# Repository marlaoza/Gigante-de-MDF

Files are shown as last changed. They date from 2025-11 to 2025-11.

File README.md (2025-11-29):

```
      _,---.   .=-.-.    _,---.   ,---.      .-._        ,--.--------.    ,----.  
  _.='.'-,  \ /==/_ /_.='.'-,  \.--.'  \    /==/ \  .-._/==/,  -   , -\,-.--` , \ 
 /==.'-     /|==|, |/==.'-     /\==\-/\ \   |==|, \/ /, |==\.-.  - ,-./==|-  _.-` 
/==/ -   .-' |==|  /==/ -   .-' /==/-|_\ |  |==|-  \|  | `--`\==\- \  |==|   `.-. 
|==|_   /_,-.|==|- |==|_   /_,-.\==\,   - \ |==| ,  | -|      \==\_ \/==/_ ,    / 
|==|  , \_.' )==| ,|==|  , \_.' )==/ -   ,| |==| -   _ |      |==|- ||==|    .-'  
\==\-  ,    (|==|- \==\-  ,    (==/-  /\ - \|==|  /\ , |      |==|, ||==|_  ,`-._ 
 /==/ _  ,  //==/. //==/ _  ,  |==\ _.\=\.-'/==/, | |- |      /==/ -//==/ ,     / 
 `--`------' `--`-` `--`------' `--`        `--`./  `--`      `--`--``--`-----``

                     ,----.                ___                  _,---.  
      _,..---._   ,-.--` , \        .-._ .'=.'\  _,..---._   .-`.' ,  \ 
    /==/,   -  \ |==|-  _.-`       /==/ \|==|  /==/,   -  \ /==/_  _.-' 
    |==|   _   _\|==|   `.-.       |==|,|  / - |==|   _   _Y==/-  '..-. 
    |==|  .=.   /==/_ ,    /       |==|  \/  , |==|  .=.   |==|_ ,    / 
    |==|,|   | -|==|    .-'        |==|- ,   _ |==|,|   | -|==|   .--'  
    |==|  '='   /==|_  ,`-._       |==| _ /\   |==|  '='   /==|-  |     
    |==|-,   _`//==/ ,     /       /==/  / / , /==|-,   _`//==/   \     
    `-.`.____.' `--`-----``        `--`./  `--``-.`.____.' `--`---'     
```

O **Gigante de MDF** é um carrinho de batalha controlado por comandos serial via **Bluetooth**, interpretados pelo USART do microcontrolador **ATmega328P**.  

O projeto inclui:
- Dois motores DC 5V controlados por um C.I L298N (movimentação)
- Um sensor **LDR** (detecção de acerto de laser)  
- Um **display de 7 segmentos** (contador de vidas)  
- Um **laser 5 V** (arma)
- Um módulo bluetooth HC-10 (controle)

## Descrição De Recursos

Todas as funcionalidades do carrinho são controladas via bytes enviados pelo HC-10.
Os comandos aceitos são:
| Comando | Ação |
|---|---|
| `f` | Move o carrinho para frente |
| `b` | Move o carrinho para trás |
| `l` | Vira o carrinho para esquerda |
| `r` | Vira o carrinho para direita |
| `p` | Para os motores |
| `m` | Troca o modo do laser para manual |
| `a` | Troca o modo do laser para automático |
| `s` | Dispara laser (no modo manual) |
| `0` | Girar 180° |
| `1` | Impulso para frente |
| `3` | Reseta vidas |
| `!` | Alterna o modo de depuração |
| `+` / `-` | Ajusta velocidade |
| `h` | Mostra os comandos |

Os motores são controlados pelo C.I de ponte H L298N, com a velocidade sendo modulada via PWM
Cada um dos motores tem um Timer diferente (*Timer0* e *Timer1*) controlando sua saida PWM.

O laser possui dois modos de operação:

### • Modo Automático  
Liga e desliga a cada 1 segundo.

### • Modo Manual  
Controlado por comando Bluetooth.  
Quando ativado, dispara por 1 segundo e entra em *cooldown* por mais 1 segundo.

O tempo do timer é controlado pelo *Timer2* do **Atmega328P** utilizando a interrupção de overflow para contar até 1 segundo

O **LDR** detecta disparos inimigos e remove vidas.  
O display de 7 segmentos exibe o número atual de vidas.

### Modo de Depuração
Quanto ativado, o **Atmega328P** envia para o HC-10 informações extras como os valores lidos pelo LDR e os resultados das interrupções

## Estrutura do Projeto
```bash
/
├── source/
│ └── main.c - Código-fonte em C do firmware
│
├── html/
│ └── Documentação HTML gerada pelo Doxygen
│
├── latex/
│ └── Documentação LaTeX gerada pelo Doxygen
│
├── schematics/
│ ├── schina-ponte-h.kicad_sch - Esquemático do KiCad
│ ├── schina-ponte-h.kicad_pcb -PCB do KiCad
│ └── circSchina.sim1 - Arquivo .simu do SimulIDE
│
└── README.md
```

## Executando no SimulIDE
1. Instale o **SimulIDE** de https://simulide.com/p/
2. Abra o arquivo schematics/circSchina.sim1 com o **SimulIDE**
3. Abra o arquivo source/main.c como código
4. Configure o arquivo como compilador avrgcc
5. Configure o compilador passando o endereço da toolchain do avr-gcc
6. no Device, coloque ATMEGA328P
7. Compile e envie o código para o microcontrolador simulado.

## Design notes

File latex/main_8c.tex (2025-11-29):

\doxysection{main.\+c File Reference}
\hypertarget{main_8c}{}\label{main_8c}\index{main.c@{main.c}}
{\ttfamily \#include $<$avr/io.\+h$>$}\newline
{\ttfamily \#include $<$avr/interrupt.\+h$>$}\newline
{\ttfamily \#include $<$util/delay.\+h$>$}\newline
\doxysubsubsection*{Macros}
\begin{DoxyCompactItemize}
\item 
\Hypertarget{main_8c_a43bafb28b29491ec7f871319b5a3b2f8}\label{main_8c_a43bafb28b29491ec7f871319b5a3b2f8} 
\#define {\bfseries F\+\_\+\+CPU}~16000000\+UL
\begin{DoxyCompactList}\small\item\em Valor do CLOCK da CPU. \end{DoxyCompactList}\item 
\Hypertarget{main_8c_a75cb54bcebb299263826f33304ad9265}\label{main_8c_a75cb54bcebb299263826f33304ad9265} 
\#define {\bfseries SEG\+\_\+A}~PB5
\item 
\Hypertarget{main_8c_a62bb65e0fd3cae8fe6bb8ca3f45b8d42}\label{main_8c_a62bb65e0fd3cae8fe6bb8ca3f45b8d42} 
\#define {\bfseries SEG\+\_\+B}~PC1
\item 
\Hypertarget{main_8c_a41810fa14a326fc41468571948dc09c4}\label{main_8c_a41810fa14a326fc41468571948dc09c4} 
\#define {\bfseries SEG\+\_\+C}~PC2
\item 
\Hypertarget{main_8c_ab408360fd13aeefc34520d9464407419}\label{main_8c_ab408360fd13aeefc34520d9464407419} 
\#define {\bfseries SEG\+\_\+D}~PC3
\item 
\Hypertarget{main_8c_af88257e7e5371478adfbb6d72366d7a1}\label{main_8c_af88257e7e5371478adfbb6d72366d7a1} 
\#define {\bfseries SEG\+\_\+E}~PC5
\item 
\Hypertarget{main_8c_abf85b76890259838df0ca7462c415848}\label{main_8c_abf85b76890259838df0ca7462c415848} 
\#define {\bfseries SEG\+\_\+G}~PC4
\item 
\Hypertarget{main_8c_a9fa6f083fd9b05ac8a6b94f34322661e}\label{main_8c_a9fa6f083fd9b05ac8a6b94f34322661e} 
\#define {\bfseries LDR}~PC0
\item 
\Hypertarget{main_8c_a7ec8393e9445109104fd54119e06fc08}\label{main_8c_a7ec8393e9445109104fd54119e06fc08} 
\#define {\bfseries LASER}~PD5
\item 
\Hypertarget{main_8c_acf59cc2c2015737f006876736aa67a52}\label{main_8c_acf59cc2c2015737f006876736aa67a52} 
\#define {\bfseries MOTOR1\+\_\+A}~PB2
\item 
\Hypertarget{main_8c_a910ad8b79b5f2ccd1024d8d46d18db59}\label{main_8c_a910ad8b79b5f2ccd1024d8d46d18db59} 
\#define {\bfseries MOTOR1\+\_\+B}~PB3
\item 
\Hypertarget{main_8c_a1b942ae1310c124145c8a7c8d486db33}\label{main_8c_a1b942ae1310c124145c8a7c8d486db33} 
\#define {\bfseries MOTOR1\+\_\+\+PWM}~PD6
\item 
\Hypertarget{main_8c_a10d9dc2baccb61a1ff9ec726e6d8925f}\label{main_8c_a10d9dc2baccb61a1ff9ec726e6d8925f} 
\#define {\bfseries MOTOR2\+\_\+A}~PB0
\item 
\Hypertarget{main_8c_a96c25b04428137f29a841f7109a924df}\label{main_8c_a96c25b04428137f29a841f7109a924df} 
\#define {\bfseries MOTOR2\+\_\+B}~PD7
\item 
\Hypertarget{main_8c_a0fcb1011ecb6d47a95a3ef79cd288b7d}\label{main_8c_a0fcb1011ecb6d47a95a3ef79cd288b7d} 
\#define {\bfseries MOTOR2\+\_\+\+PWM}~PB1
\item 
\Hypertarget{main_8c_a0272d814b1a09a8eb6511318febe3826}\label{main_8c_a0272d814b1a09a8eb6511318febe3826} 
\#define {\bfseries TIME\+\_\+180}~200
\begin{DoxyCompactList}\small\item\em Tempo necessário para a volta de 180 graus. (em ms). \end{DoxyCompactList}\item 
\Hypertarget{main_8c_a34901744643d83cff09d9e727d652613}\label{main_8c_a34901744643d83cff09d9e727d652613} 
\#define {\bfseries RX\+\_\+\+COMPLETE\+\_\+\+INTERRUPT}~(1$<$$<$RXCIE0)
\item 
\Hypertarget{main_8c_a5d8a218998fd7a223d3a907ea2a16a81}\label{main_8c_a5d8a218998fd7a223d3a907ea2a16a81} 
\#define {\bfseries DATA\+\_\+\+REGISTER\+\_\+\+EMPTY\+\_\+\+INTERRUPT}~(1$<$$<$UDRIE0)
\item 
\Hypertarget{main_8c_a0f80e758504093c7a4ad6a2f03dca9eb}\label{main_8c_a0f80e758504093c7a4ad6a2f03dca9eb} 
\#define {\bfseries LASEROVERFLOWS}~62
\begin{DoxyCompactList}\small\item\em Valor necessário de overflows para timer de 1.\+01 segundos. \end{DoxyCompactList}\item 
\Hypertarget{main_8c_aa3d51a5b2e2f0230c8596408a964e102}\label{main_8c_aa3d51a5b2e2f0230c8596408a964e102} 
\#define {\bfseries max\+Life}~3
\begin{DoxyCompactList}\small\item\em Valor máximo de vidas. \end{DoxyCompactList}\item 
\Hypertarget{main_8c_a52d1225092b1f6d624fb219ecb7d1b0f}\label{main_8c_a52d1225092b1f6d624fb219ecb7d1b0f} 
\#define {\bfseries LDR\+\_\+\+THRESHOLD}~900
\begin{DoxyCompactList}\small\item\em Valor mínimo de detecção do LDR. \end{DoxyCompactList}\end{DoxyCompactItemize}
\doxysubsubsection*{Functions}
\begin{DoxyCompactItemize}
\item 
void \mbox{\hyperlink{main_8c_a11fdda93ffc5c981f0e96d972f65fd9d}{set\+Bit}} (volatile uint8\+\_\+t \texorpdfstring{$\ast$}{*}port, uint8\+\_\+t bit, uint8\+\_\+t value)
\item 
void \mbox{\hyperlink{main_8c_a280241753f4a0dd95120a19faa8494f2}{setup\+USART}} (uint32\+\_\+t value)
\item 
void \mbox{\hyperlink{main_8c_a8678855112cc7afd943a34b9f9a64559}{send\+Byte\+USART}} (uint8\+\_\+t Data\+Byte)
\item 
void \mbox{\hyperlink{main_8c_ac727172e4fc219fb8fab11caf3d08e3a}{write\+USART}} (uint8\+\_\+t \texorpdfstring{$\ast$}{*}str)
\item 
void \mbox{\hyperlink{main_8c_ab003fa8d991f012095e004b6e9d729a7}{setup\+Motors\+Pwm}} ()
\item 
void \mbox{\hyperlink{main_8c_aacea78a29b4d1d7a45f395c472284bf1}{set\+Motor1}} (uint8\+\_\+t pinA, uint8\+\_\+t pinB, uint8\+\_\+t cycle)
\item 
void \mbox{\hyperlink{main_8c_a59e3d8a543871c2732f89c4a45aa8a3a}{set\+Motor2}} (uint8\+\_\+t pinA, uint8\+\_\+t pinB, uint8\+\_\+t cycle)
\item 
void \mbox{\hyperlink{main_8c_a8fd656f5258403d0cf14a869fad9d86d}{setup\+Laser\+Timer}} ()
\item 
\mbox{\hyperlink{main_8c_a7cfcbe42bd266750aeb6e5d71e5ea479}{ISR}} (TIMER2\+\_\+\+OVF\+\_\+vect)
\item 
void \mbox{\hyperlink{main_8c_aa3912aa6df5e81d539cf9f0709cb765f}{shoot}} ()
\item 
void \mbox{\hyperlink{main_8c_a13ee2855717b7f2765142c6362473f18}{update\+Life}} ()
\item 
void \mbox{\hyperlink{main_8c_a4219fa21765083266972a7de4b2dabe5}{remove\+Life}} ()
\item 
void \mbox{\hyperlink{main_8c_a333cf77c1bcac15ce042e8a8de73eab1}{reset\+Life}} ()
\item 
void \mbox{\hyperlink{main_8c_a823993b1d47cd88ec002226cbb45ff29}{setup\+ADC}} ()
\item 
uint16\+\_\+t \mbox{\hyperlink{main_8c_a1202dca577f673604816abd4f250a7a6}{read\+LDR}} ()
\item 
void \mbox{\hyperlink{main_8c_a60de64d75454385b23995437f1d72669}{start}} ()
\item 
\mbox{\hyperlink{main_8c_a09ce999e15ad60b8a3f07d08af1946f9}{ISR}} (USART\+\_\+\+RX\+\_\+vect)
\item 
int \mbox{\hyperlink{main_8c_a840291bc02cba5474a4cb46a9b9566fe}{main}} (void)
\end{DoxyCompactItemize}
\doxysubsubsection*{Variables}
\begin{DoxyCompactItemize}
\item 
\Hypertarget{main_8c_a321f56e9e77670ef4357fd2fac109e89}\label{main_8c_a321f56e9e77670ef4357fd2fac109e89} 
uint8\+\_\+t {\bfseries alive} = 1
\begin{DoxyCompactList}\small\item\em Flag que determina se o gigante esta vivo. \end{DoxyCompactList}\item 
\Hypertarget{main_8c_a52c99903aeb24336693ca32035cc2ae6}\label{main_8c_a52c99903aeb24336693ca32035cc2ae6} 
uint8\+\_\+t {\bfseries debug} = 0
\begin{DoxyCompactList}\small\item\em Flag que determina se o modo de depuração está ativo. \end{DoxyCompactList}\item 
\Hypertarget{main_8c_ada99b38cbfa653297f6e4ff2daac9346}\label{main_8c_ada99b38cbfa653297f6e4ff2daac9346} 
uint8\+\_\+t {\bfseries laser\+Cooldown} = 0
\begin{DoxyCompactList}\small\item\em Flag que determina se o laser esta em cooldown (não pode ser ativado). \end{DoxyCompactList}\item 
\Hypertarget{main_8c_a5a28f50e37c449a2611bd6391e990536}\label{main_8c_a5a28f50e37c449a2611bd6391e990536} 
uint8\+\_\+t {\bfseries laser\+Auto} = 1
\begin{DoxyCompactList}\small\item\em Flag que controla o modo do motor (1 -\/ AUTO, 2 -\/ MANUAL). \end{DoxyCompactList}\item 
\Hypertarget{main_8c_a77f2d863dcbba3378f384b35b75622e6}\label{main_8c_a77f2d863dcbba3378f384b35b75622e6} 
volatile uint16\+\_\+t {\bfseries laser\+Counter} = 0
\begin{DoxyCompactList}\small\item\em Contador de overflows do Timer do Motor. \end{DoxyCompactList}\item 
\Hypertarget{main_8c_a5694338c1bcb4455072af4179913d44d}\label{main_8c_a5694338c1bcb4455072af4179913d44d} 
uint8\+\_\+t {\bfseries life} = 3
\begin{DoxyCompactList}\small\item\em Valor atual de vidas. \end{DoxyCompactList}\item 
const uint8\+\_\+t \mbox{\hyperlink{main_8c_af9a05193da56d61350f9602f9ce30491}{life\+Display}} \mbox{[}$\,$\mbox{]}
\begin{DoxyCompactList}\small\item\em Lista com a configuração do led de 7 segmentos para cada número de vidas. \end{DoxyCompactList}\item 
\Hypertarget{main_8c_a03fe4605425aef04f4dad440784dbf45}\label{main_8c_a03fe4605425aef04f4dad440784dbf45} 
int {\bfseries SPEED} = 200
\begin{DoxyCompactList}\small\item\em Valor da velocidade do carrinho. \end{DoxyCompactList}\item 
\Hypertarget{main_8c_abb2121f4a82952f874c58aa05c31bb81}\label{main_8c_abb2121f4a82952f874c58aa05c31bb81} 
volatile uint8\+\_\+t {\bfseries data\+USART}
\begin{DoxyCompactList}\small\item\em Byte que guarda a mensagem que vai ser lida pelo USART. \end{DoxyCompactList}\item 
\Hypertarget{main_8c_a4b92294b4e82a7d875de15a7c2f804b3}\label{main_8c_a4b92294b4e82a7d875de15a7c2f804b3} 
char {\bfseries buffer} \mbox{[}6\mbox{]}
\begin{DoxyCompactList}\small\item\em Buffer 6 bytes para guardar valor lido do LDR convertido para String. \end{DoxyCompactList}\end{DoxyCompactItemize}

\label{doc-func-members}
\Hypertarget{main_8c_doc-func-members}
\doxysubsection{Function Documentation}
\Hypertarget{main_8c_a7cfcbe42bd266750aeb6e5d71e5ea479}\index{main.c@{main.c}!ISR@{ISR}}
\index{ISR@{ISR}!main.c@{main.c}}
\doxysubsubsection{\texorpdfstring{ISR()}{ISR()}\hspace{0.1cm}{\footnotesize\ttfamily [1/2]}}
{\footnotesize\ttfamily \label{main_8c_a7cfcbe42bd266750aeb6e5d71e5ea479} 
ISR (\begin{DoxyParamCaption}\item[{TIMER2\+\_\+\+OVF\+\_\+vect}]{}{}\end{DoxyParamCaption})}

Interrupção de controle do Timer2 Quando laser\+Counter for maior ou igual a LASEROVERFLOWS um segundo se passou Controla o laser, caso em modo automático, ligando e desligando intercaladamente Caso em modo manual, desligando após um segundo e configurando o
\begin{DoxyParams}{Parameters}
{\em laser\+Cooldown} & \\
\hline
\end{DoxyParams}
\Hypertarget{main_8c_a09ce999e15ad60b8a3f07d08af1946f9}\index{main.c@{main.c}!ISR@{ISR}}
\index{ISR@{ISR}!main.c@{main.c}}
\doxysubsubsection{\texorpdfstring{ISR()}{ISR()}\hspace{0.1cm}{\footnotesize\ttfamily [2/2]}}
{\footnotesize\ttfamily \label{main_8c_a09ce999e15ad60b8a3f07d08af1946f9} 
ISR (\begin{DoxyParamCaption}\item[{USART\+\_\+\+RX\+\_\+vect}]{}{}\end{DoxyParamCaption})}

Interrupção que lida com as mensagens do USART, interpretando os dados para controlar o robô \Hypertarget{main_8c_a840291bc02cba5474a4cb46a9b9566fe}\index{main.c@{main.c}!main@{main}}
\index{main@{main}!main.c@{main.c}}
\doxysubsubsection{\texorpdfstring{main()}{main()}}
{\footnotesize\ttfamily \label{main_8c_a840291bc02cba5474a4cb46a9b9566fe} 
int main (\begin{DoxyParamCaption}\item[{void}]{}{}\end{DoxyParamCaption})}

Função de Entrada \Hypertarget{main_8c_a1202dca577f673604816abd4f250a7a6}\index{main.c@{main.c}!readLDR@{readLDR}}
\index{readLDR@{readLDR}!main.c@{main.c}}
\doxysubsubsection{\texorpdfstring{readLDR()}{readLDR()}}
{\footnotesize\ttfamily \label{main_8c_a1202dca577f673604816abd4f250a7a6} 
uint16\+\_\+t read\+LDR (\begin{DoxyParamCaption}{}{}\end{DoxyParamCaption})}

Aguarda a conversão e retorna a leitura do conversor analógico digital para o pino PC0 \begin{DoxyReturn}{Returns}
leitura do pino PC0 de 10 bits (0–1023) 
\end{DoxyReturn}
\Hypertarget{main_8c_a4219fa21765083266972a7de4b2dabe5}\index{main.c@{main.c}!removeLife@{removeLife}}
\index{removeLife@{removeLife}!main.c@{main.c}}
\doxysubsubsection{\texorpdfstring{removeLife()}{removeLife()}}
{\footnotesize\ttfamily \label{main_8c_a4219fa21765083266972a7de4b2dabe5} 
void remove\+Life (\begin{DoxyParamCaption}{}{}\end{DoxyParamCaption})}

Remove uma vida e realiza a rotina de perda de vida (rodar 180 graus e desativar por 5 segundos) Caso não existam mais vidas para remover, desliga os motores e seta
\begin{DoxyParams}{Parameters}
{\em alive} & para 0 \\
\hline
\end{DoxyParams}
\Hypertarget{main_8c_a333cf77c1bcac15ce042e8a8de73eab1}\index{main.c@{main.c}!resetLife@{resetLife}}
\index{resetLife@{resetLife}!main.c@{main.c}}
\doxysubsubsection{\texorpdfstring{resetLife()}{resetLife()}}
{\footnotesize\ttfamily \label{main_8c_a333cf77c1bcac15ce042e8a8de73eab1} 
void reset\+Life (\begin{DoxyParamCaption}{}{}\end{DoxyParamCaption})}

Recarrega as vidas para o valor máximo e seta
\begin{DoxyParams}{Parameters}
{\em alive} & para 1 \\
\hline
\end{DoxyParams}
\Hypertarget{main_8c_a8678855112cc7afd943a34b9f9a64559}\index{main.c@{main.c}!sendByteUSART@{sendByteUSART}}
\index{sendByteUSART@{sendByteUSART}!main.c@{main.c}}
\doxysubsubsection{\texorpdfstring{sendByteUSART()}{sendByteUSART()}}
{\footnotesize\ttfamily \label{main_8c_a8678855112cc7afd943a34b9f9a64559} 
void send\+Byte\+USART (\begin{DoxyParamCaption}\item[{uint8\+\_\+t}]{Data\+Byte}{}\end{DoxyParamCaption})}

Envia um byte por meio do USART 
\begin{DoxyParams}[1]{Parameters}
\mbox{\texttt{in}}  & {\em Data\+Byte} & \\
\hline
\end{DoxyParams}
\Hypertarget{main_8c_a11fdda93ffc5c981f0e96d972f65fd9d}\index{main.c@{main.c}!setBit@{setBit}}
\index{setBit@{setBit}!main.c@{main.c}}
\doxysubsubsection{\texorpdfstring{setBit()}{setBit()}}
{\footnotesize\ttfamily \label{main_8c_a11fdda93ffc5c981f0e96d972f65fd9d} 
void set\+Bit (\begin{DoxyParamCaption}\item[{volatile uint8\+\_\+t \texorpdfstring{$\ast$}{*}}]{port}{, }\item[{uint8\+\_\+t}]{bit}{, }\item[{uint8\+\_\+t}]{value}{}\end{DoxyParamCaption})}

Seta um valor a um bit específicio limpando esse bit e fazendo uma comparação OR com o valor dado 
\begin{DoxyParams}[1]{Parameters}
\mbox{\texttt{in}}  & {\em \texorpdfstring{$\ast$}{*}port} & \\
\hline
\mbox{\texttt{in}}  & {\em bit} & \\
\hline
\mbox{\texttt{in}}  & {\em value} & \\
\hline
\end{DoxyParams}
\Hypertarget{main_8c_aacea78a29b4d1d7a45f395c472284bf1}\index{main.c@{main.c}!setMotor1@{setMotor1}}
\index{setMotor1@{setMotor1}!main.c@{main.c}}
\doxysubsubsection{\texorpdfstring{setMotor1()}{setMotor1()}}
{\footnotesize\ttfamily \label{main_8c_aacea78a29b4d1d7a45f395c472284bf1} 
void set\+Motor1 (\begin{DoxyParamCaption}\item[{uint8\+\_\+t}]{pinA}{, }\item[{uint8\+\_\+t}]{pinB}{, }\item[{uint8\+\_\+t}]{cycle}{}\end{DoxyParamCaption})}

Seta os valores do Pino A, Pino B e o duty cycle do PWM para o Motor 1 pinA e pinB controlam a direção (1 0 frente, 0 1 traz) e o freio (0 0 para, 1 1 para) Duty cicle controla a velocidade do motor 
\begin{DoxyParams}[1]{Parameters}
\mbox{\texttt{in}}  & {\em pinA} & \\
\hline
\mbox{\texttt{in}}  & {\em pinB} & \\
\hline
\mbox{\texttt{in}}  & {\em cycle} & \\
\hline
\end{DoxyParams}
\Hypertarget{main_8c_a59e3d8a543871c2732f89c4a45aa8a3a}\index{main.c@{main.c}!setMotor2@{setMotor2}}
\index{setMotor2@{setMotor2}!main.c@{main.c}}
\doxysubsubsection{\texorpdfstring{setMotor2()}{setMotor2()}}
{\footnotesize\ttfamily \label{main_8c_a59e3d8a543871c2732f89c4a45aa8a3a} 
void set\+Motor2 (\begin{DoxyParamCaption}\item[{uint8\+\_\+t}]{pinA}{, }\item[{uint8\+\_\+t}]{pinB}{, }\item[{uint8\+\_\+t}]{cycle}{}\end{DoxyParamCaption})}

Seta os valores do Pino A, Pino B e o duty cycle do PWM para o Motor 2 pinA e pinB controlam a direção (1 0 frente, 0 1 traz) e o freio (0 0 para, 1 1 para) Duty cicle controla a velocidade do motor 
\begin{DoxyParams}[1]{Parameters}
\mbox{\texttt{in}}  & {\em pinA} & \\
\hline
\mbox{\texttt{in}}  & {\em pinB} & \\
\hline
\mbox{\texttt{in}}  & {\em cycle} & \\
\hline
\end{DoxyParams}
\Hypertarget{main_8c_a823993b1d47cd88ec002226cbb45ff29}\index{main.c@{main.c}!setupADC@{setupADC}}
\index{setupADC@{setupADC}!main.c@{main.c}}
\doxysubsubsection{\texorpdfstring{setupADC()}{setupADC()}}
{\footnotesize\ttfamily \label{main_8c_a823993b1d47cd88ec002226cbb45ff29} 
void setup\+ADC (\begin{DoxyParamCaption}{}{}\end{DoxyParamCaption})}

Configura e inicia o conversor analógico digital \Hypertarget{main_8c_a8fd656f5258403d0cf14a869fad9d86d}\index{main.c@{main.c}!setupLaserTimer@{setupLaserTimer}}
\index{setupLaserTimer@{setupLaserTimer}!main.c@{main.c}}
\doxysubsubsection{\texorpdfstring{setupLaserTimer()}{setupLaserTimer()}}
{\footnotesize\ttfamily \label{main_8c_a8fd656f5258403d0cf14a869fad9d86d} 
void setup\+Laser\+Timer (\begin{DoxyParamCaption}{}{}\end{DoxyParamCaption})}

Configura e inicializa o Timer2 \Hypertarget{main_8c_ab003fa8d991f012095e004b6e9d729a7}\index{main.c@{main.c}!setupMotorsPwm@{setupMotorsPwm}}
\index{setupMotorsPwm@{setupMotorsPwm}!main.c@{main.c}}
\doxysubsubsection{\texorpdfstring{setupMotorsPwm()}{setupMotorsPwm()}}
{\footnotesize\ttfamily \label{main_8c_ab003fa8d991f012095e004b6e9d729a7} 
void setup\+Motors\+Pwm (\begin{DoxyParamCaption}{}{}\end{DoxyParamCaption})}

Configura e inicializa o PWM com Fast\+PWM Motor 1 -\/ TIMER 0 PORTA A (PD6) Motor 2 -\/ TIMER 1 PORTA A (PB1) \Hypertarget{main_8c_a280241753f4a0dd95120a19faa8494f2}\index{main.c@{main.c}!setupUSART@{setupUSART}}
\index{setupUSART@{setupUSART}!main.c@{main.c}}
\doxysubsubsection{\texorpdfstring{setupUSART()}{setupUSART()}}
{\footnotesize\ttfamily \label{main_8c_a280241753f4a0dd95120a19faa8494f2} 
void setup\+USART (\begin{DoxyParamCaption}\item[{uint32\+\_\+t}]{value}{}\end{DoxyParamCaption})}

Configura e inicializa o USART com a BAUD\+\_\+\+RATE fornecida 
\begin{DoxyParams}[1]{Parameters}
\mbox{\texttt{in}}  & {\em value} & \\
\hline
\end{DoxyParams}
\Hypertarget{main_8c_aa3912aa6df5e81d539cf9f0709cb765f}\index{main.c@{main.c}!shoot@{shoot}}
\index{shoot@{shoot}!main.c@{main.c}}
\doxysubsubsection{\texorpdfstring{shoot()}{shoot()}}
{\footnotesize\ttfamily \label{main_8c_aa3912aa6df5e81d539cf9f0709cb765f} 
void shoot (\begin{DoxyParamCaption}{}{}\end{DoxyParamCaption})}

Controle de ativação do laser Caso laser\+Cooldown esteja em 0, ativa o laser e reinicia laser\+Counter \Hypertarget{main_8c_a60de64d75454385b23995437f1d72669}\index{main.c@{main.c}!start@{start}}
\index{start@{start}!main.c@{main.c}}
\doxysubsubsection{\texorpdfstring{start()}{start()}}
{\footnotesize\ttfamily \label{main_8c_a60de64d75454385b23995437f1d72669} 
void start (\begin{DoxyParamCaption}{}{}\end{DoxyParamCaption})}

Função de configuração principal, seta os pinos como saída ou entrada e chama as funções de setup \Hypertarget{main_8c_a13ee2855717b7f2765142c6362473f18}\index{main.c@{main.c}!updateLife@{updateLife}}
\index{updateLife@{updateLife}!main.c@{main.c}}
\doxysubsubsection{\texorpdfstring{updateLife()}{updateLife()}}
{\footnotesize\ttfamily \label{main_8c_a13ee2855717b7f2765142c6362473f18} 
void update\+Life (\begin{DoxyParamCaption}{}{}\end{DoxyParamCaption})}

Atualiza o valor do display de 7 segmentos que representa a vida \Hypertarget{main_8c_ac727172e4fc219fb8fab11caf3d08e3a}\index{main.c@{main.c}!writeUSART@{writeUSART}}
\index{writeUSART@{writeUSART}!main.c@{main.c}}
\doxysubsubsection{\texorpdfstring{writeUSART()}{writeUSART()}}
{\footnotesize\ttfamily \label{main_8c_ac727172e4fc219fb8fab11caf3d08e3a} 
void write\+USART (\begin{DoxyParamCaption}\item[{uint8\+\_\+t \texorpdfstring{$\ast$}{*}}]{str}{}\end{DoxyParamCaption})}

Envia uma string ou cadeia de bytes completa por meio do USART 
\begin{DoxyParams}[1]{Parameters}
\mbox{\texttt{in}}  & {\em str} & \\
\hline
\end{DoxyParams}

\label{doc-var-members}
\Hypertarget{main_8c_doc-var-members}
\doxysubsection{Variable Documentation}
\Hypertarget{main_8c_af9a05193da56d61350f9602f9ce30491}\index{main.c@{main.c}!lifeDisplay@{lifeDisplay}}
\index{lifeDisplay@{lifeDisplay}!main.c@{main.c}}
\doxysubsubsection{\texorpdfstring{lifeDisplay}{lifeDisplay}}
{\footnotesize\ttfamily \label{main_8c_af9a05193da56d61350f9602f9ce30491} 
const uint8\+\_\+t life\+Display\mbox{[}$\,$\mbox{]}}

{\bfseries Initial value\+:}
\begin{DoxyCode}{0}
\DoxyCodeLine{=\ \{}
\DoxyCodeLine{\ \ \ \ }
\DoxyCodeLine{\ \ \ \ 0b00000000,}
\DoxyCodeLine{\ \ \ \ 0b00000110,}
\DoxyCodeLine{\ \ \ \ 0b00111011,}
\DoxyCodeLine{\ \ \ \ 0b00011111,}
\DoxyCodeLine{\}}

\end{DoxyCode}

Lista com a configuração do led de 7 segmentos para cada número de vidas.

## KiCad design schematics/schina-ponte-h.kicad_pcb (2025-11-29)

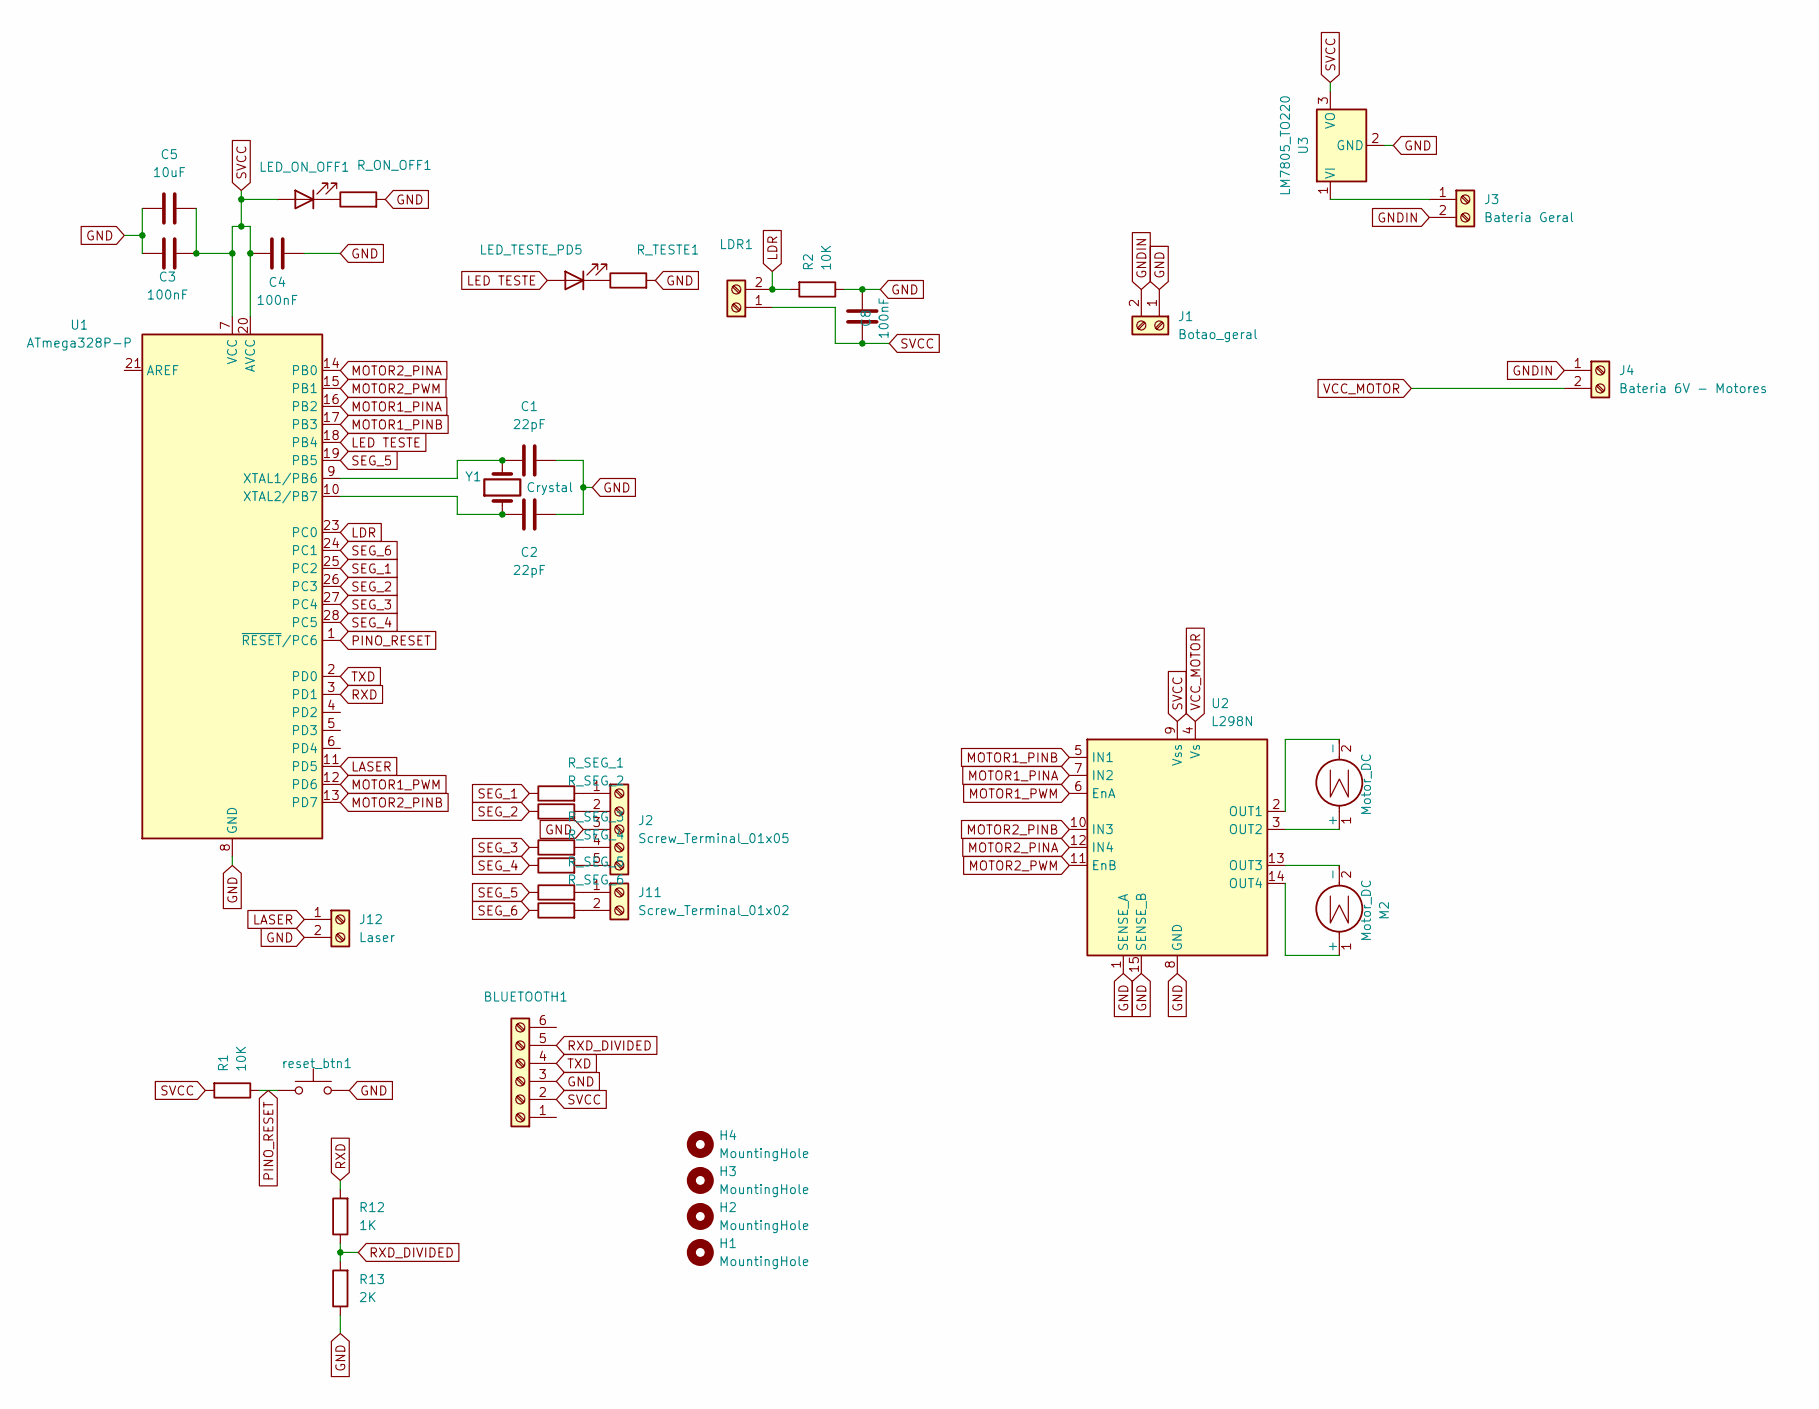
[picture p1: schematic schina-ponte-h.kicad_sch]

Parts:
BLUETOOTH1: Screw_Terminal_01x06; PinHeader_1x06_P2.54mm_Vertical
C1, C2: 22pF; CP_Radial_Tantal_D10.5mm_P5.00mm
C3, C4, C8: 100nF; CP_Radial_Tantal_D10.5mm_P5.00mm
C5: 10uF; CP_Radial_D10.0mm_P3.80mm
H1, H2, H3, H4: MountingHole; MountingHole_3.2mm_M3
J1: Botao_geral; TerminalBlock_MaiXu_MX126-5.0-02P_1x02_P5.00mm
J2: Screw_Terminal_01x05; JST_XH_B5B-XH-A_1x05_P2.50mm_Vertical
J3: Bateria Geral; JST_XH_B2B-XH-A_1x02_P2.50mm_Vertical
J4: Bateria 6V - Motores; JST_XH_B2B-XH-A_1x02_P2.50mm_Vertical
J11: Screw_Terminal_01x02; JST_XH_B2B-XH-A_1x02_P2.50mm_Vertical
J12: Laser; JST_XH_B2B-XH-A_1x02_P2.50mm_Vertical
LDR1: JST_XH_B2B-XH-A_1x02_P2.50mm_Vertical
LED_ON_OFF1: LED ARDUINO ON OFF; LED_D3.0mm
LED_TESTE_PD5: LED; LED_D3.0mm
M1, M2: Motor_DC; JST_XH_B2B-XH-A_1x02_P2.50mm_Vertical
R1, R2: 10K; R_Axial_DIN0207_L6.3mm_D2.5mm_P15.24mm_Horizontal
R12: 1K; R_Axial_DIN0207_L6.3mm_D2.5mm_P15.24mm_Horizontal
R13: 2K; R_Axial_DIN0207_L6.3mm_D2.5mm_P15.24mm_Horizontal
R_ON_OFF1: RESISTOR LED ON OFF; R_Axial_DIN0207_L6.3mm_D2.5mm_P15.24mm_Horizontal
R_SEG_1, R_SEG_2, R_SEG_3, R_SEG_4, R_SEG_5, R_SEG_6: RESISTOR LED TESTE; R_Axial_DIN0207_L6.3mm_D2.5mm_P15.24mm_Horizontal
R_TESTE1: RESISTOR LED TESTE; R_Axial_DIN0207_L6.3mm_D2.5mm_P15.24mm_Horizontal
U1: ATmega328P-P; DIP-28_W7.62mm_LongPads
U2: L298N; TO-220-15_P2.54x5.08mm_StaggerOdd_Lead4.58mm_Vertical
U3: LM7805_TO220; TO-220-3_Vertical
Y1: Crystal; Crystal_HC18-U_Vertical
reset_btn1: FREIO EMERGENCIA; SW_PUSH-12mm

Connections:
GND: BLUETOOTH1.3, C1.2, C2.2, C3.1, C4.2, C5.1, C8.2, J1.1, J2.3, J12.2, R2.1, R13.1, R_ON_OFF1.2, R_TESTE1.2, U1.8 (GND), U1.22 (GND), U2.1 (SENSE_A), U2.8 (GND), U2.15 (SENSE_B), U3.2 (GND), reset_btn1.2
GNDIN: J1.2, J3.2, J4.1
LASER: J12.1, U1.11 (PD5)
LDR: LDR1.2, R2.2, U1.23 (PC0)
LED TESTE: LED_TESTE_PD5.2 (A), U1.18 (PB4)
MOTOR1_PINA: U1.16 (PB2), U2.7 (IN2)
MOTOR1_PINB: U1.17 (PB3), U2.5 (IN1)
MOTOR1_PWM: U1.12 (PD6), U2.6 (EnA)
MOTOR2_PINA: U1.14 (PB0), U2.12 (IN4)
MOTOR2_PINB: U1.13 (PD7), U2.10 (IN3)
MOTOR2_PWM: U1.15 (PB1), U2.11 (EnB)
unnamed: J2.1, R_SEG_1.2
unnamed: J2.2, R_SEG_2.2
unnamed: J2.4, R_SEG_3.2
unnamed: J2.5, R_SEG_4.2
unnamed: J3.1, U3.1 (VI)
unnamed: J11.1, R_SEG_5.2
unnamed: J11.2, R_SEG_6.2
unnamed: LED_ON_OFF1.1 (K), R_ON_OFF1.1
unnamed: LED_TESTE_PD5.1 (K), R_TESTE1.1
unnamed: M1.1 (+), U2.3 (OUT2)
unnamed: M1.2 (-), U2.2 (OUT1)
unnamed: M2.1 (+), U2.14 (OUT4)
unnamed: M2.2 (-), U2.13 (OUT3)
unnamed: C1.1, U1.9 (XTAL1/PB6), Y1.2
unnamed: C2.1, U1.10 (XTAL2/PB7), Y1.1
PINO_RESET: R1.1, U1.1 (~RESET/PC6), reset_btn1.1
RXD: R12.2, U1.3 (PD1)
RXD_DIVIDED: BLUETOOTH1.5, R12.1, R13.2
SEG_1: R_SEG_1.1, U1.25 (PC2)
SEG_2: R_SEG_2.1, U1.26 (PC3)
SEG_3: R_SEG_3.1, U1.27 (PC4)
SEG_4: R_SEG_4.1, U1.28 (PC5)
SEG_5: R_SEG_5.1, U1.19 (PB5)
SEG_6: R_SEG_6.1, U1.24 (PC1)
SVCC: BLUETOOTH1.2, C3.2, C4.1, C5.2, C8.1, LDR1.1, LED_ON_OFF1.2 (A), R1.2, U1.7 (VCC), U1.20 (AVCC), U2.9 (Vss), U3.3 (VO)
TXD: BLUETOOTH1.4, U1.2 (PD0)
VCC_MOTOR: J4.2, U2.4 (Vs)

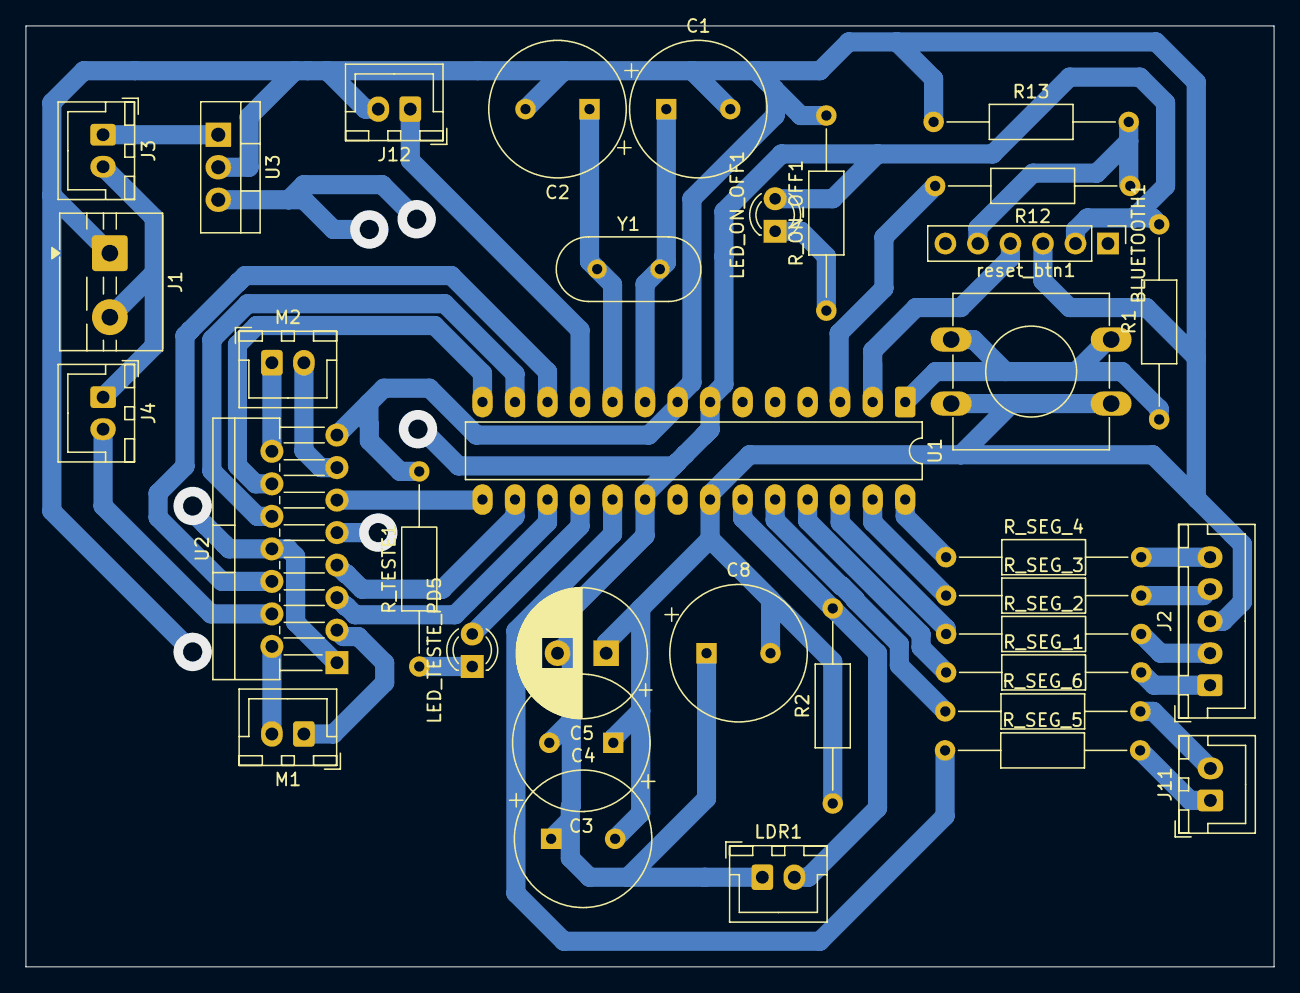
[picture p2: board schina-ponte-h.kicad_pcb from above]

Board: 2 copper layers, 97.5 x 73.5 mm, 39 parts (0 on the bottom side), 38 nets.

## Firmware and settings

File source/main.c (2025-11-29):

/// @file main.c
#include <avr/io.h>
#include <avr/interrupt.h>

#define F_CPU 16000000UL ///< Valor do CLOCK da CPU.

#include <util/delay.h>

#define SEG_A PB5
#define SEG_B PC1
#define SEG_C PC2
#define SEG_D PC3
#define SEG_E PC5
#define SEG_G PC4

#define LDR PC0

#define LASER PD5

#define MOTOR1_A PB2
#define MOTOR1_B PB3
#define MOTOR1_PWM PD6

#define MOTOR2_A PB0
#define MOTOR2_B PD7
#define MOTOR2_PWM PB1

#define TIME_180 200 ///< Tempo necessário para a volta de 180 graus. (em ms)

uint8_t alive = 1; ///< Flag que determina se o gigante esta vivo.
uint8_t debug = 0; ///< Flag que determina se o modo de depuração está ativo.

/**
 * Seta um valor a um bit específicio limpando esse bit e fazendo uma comparação OR com o valor dado
 * @param[in] *port
 * @param[in] bit
 * @param[in] value
 */ 
void setBit (volatile uint8_t *port, uint8_t bit, uint8_t value){
	*port = (*port & ~(1 << bit)) | (value << bit);
}


#define RX_COMPLETE_INTERRUPT (1<<RXCIE0)
#define DATA_REGISTER_EMPTY_INTERRUPT (1<<UDRIE0)

/**
 * Configura e inicializa o USART com a BAUD_RATE fornecida
 * @param[in] value
 */ 
void setupUSART(uint32_t value){

	uint16_t BAUD_PRESCALER = (F_CPU / (value * 16UL)) - 1; 

	UBRR0H = BAUD_PRESCALER >> 8;
	UBRR0L = BAUD_PRESCALER;
	
	UCSR0C = (0 << UMSEL00) | (0<<UPM00) | (0<<USBS0) | (3<<UCSZ00);
	
	UCSR0B = (1 << RXEN0) | (1 << TXEN0);
}

/**
 * Envia um byte por meio do USART
 * @param[in] DataByte
 */ 
void sendByteUSART(uint8_t DataByte){
	while( (UCSR0A & (1 << UDRE0)) == 0 ) {};
	UDR0 = DataByte;
}

/**
 * Envia uma string ou cadeia de bytes completa por meio do USART
 * @param[in] str
 */ 
void writeUSART(uint8_t * str) {
	str = str + '\0';
	uint8_t c = 1;
	int aux = 0;
	while(c != '\0'){
		c = str[aux];
		sendByteUSART(c);
		aux++;

	}
}



/**
 * Configura e inicializa o PWM com FastPWM
 * Motor 1 - TIMER 0 PORTA A (PD6)
 * Motor 2 - TIMER 1 PORTA A (PB1)
 */ 
void setupMotorsPwm(){
	TCCR0A = (1 << WGM00) | (1 << WGM01) | (1 << COM0A1);   
	TCCR0B = (1 << CS01);
	OCR0A = 0;
	
	TCCR1A = (1 << WGM10) | (1 << COM1A1);
	TCCR1B = (1 << WGM12) | (1 << CS11);
	OCR1A = 0;
}

/**
 * Seta os valores do Pino A, Pino B e o duty cycle do PWM para o Motor 1
 * pinA e pinB controlam a direção (1 0 frente, 0 1 traz) e o freio (0 0 para, 1 1 para)
 * Duty cicle controla a velocidade do motor
 * @param[in] pinA
 * @param[in] pinB
 * @param[in] cycle
 */ 
void setMotor1(uint8_t pinA, uint8_t pinB, uint8_t cycle){
	setBit(&PORTB, MOTOR1_A, pinA);
	setBit(&PORTB, MOTOR1_B, pinB);
	OCR0A = cycle;
}

/**
 * Seta os valores do Pino A, Pino B e o duty cycle do PWM para o Motor 2
 * pinA e pinB controlam a direção (1 0 frente, 0 1 traz) e o freio (0 0 para, 1 1 para)
 * Duty cicle controla a velocidade do motor
 * @param[in] pinA
 * @param[in] pinB
 * @param[in] cycle
 */ 
void setMotor2(uint8_t pinA, uint8_t pinB, uint8_t cycle){
	setBit(&PORTB, MOTOR2_A, pinA);
	setBit(&PORTD, MOTOR2_B, pinB);
	OCR1A = cycle;
}

uint8_t laserCooldown = 0; ///< Flag que determina se o laser esta em cooldown (não pode ser ativado).
uint8_t laserAuto = 1; ///< Flag que controla o modo do motor (1 - AUTO, 2 - MANUAL).

volatile uint16_t laserCounter = 0; ///< Contador de overflows do Timer do Motor

//16 mhz / 1024 prescaler= 15625HZ
// 1/ 15625HZ = 0.000064s
// 255 *  0.000064s = 0.01632s;
// 1 / 0.01632 = 61.2745098039;
//62 = 1.012 segundos
	
#define LASEROVERFLOWS 62 ///< Valor necessário de overflows para timer de 1.01 segundos

/**
 * Configura e inicializa o Timer2
 */ 
void setupLaserTimer() {
	TCCR2A = 0;          
    TCCR2B = (1 << CS22) | (1 << CS21) | (1 << CS20); 
    TIMSK2 = (1 << TOIE2);
}

/**
 * Interrupção de controle do Timer2
 * Quando laserCounter for maior ou igual a LASEROVERFLOWS um segundo se passou
 * Controla o laser, caso em modo automático, ligando e desligando intercaladamente
 * Caso em modo manual, desligando após um segundo e configurando o @param laserCooldown
 */ 
ISR(TIMER2_OVF_vect) {
	if(debug){
		writeUSART("OVERFLOW TIMER2 \n");
	}
	
	laserCounter++;
	
	if(laserCounter >= LASEROVERFLOWS){
		if(debug){
			writeUSART("1.012 segundos timer2 \n");
		}
		
		if(laserAuto){
			PORTD ^= (1 << LASER);
		}else{	
			if(PIND & (1 << LASER)){
				PORTD &= ~(1 << LASER);
			}else{
				laserCooldown = 0;
			}
		}		
		laserCounter = 0;
	}
	
}


/**
 * Controle de ativação do laser
 * Caso laserCooldown esteja em 0, ativa o laser e reinicia laserCounter
 */ 
void shoot() {
	if(!laserCooldown){
		PORTD |= (1 << LASER);
		laserCounter = 0;
		laserCooldown = 1;
	}else{
		writeUSART("ARMA EM COOLDOWN \n");
	}
}


#define maxLife 3 ///< Valor máximo de vidas
uint8_t life = 3; ///< Valor atual de vidas

const uint8_t lifeDisplay[] = {
	//- - E G D C B (A)
	0b00000000,
	0b00000110,
	0b00111011,
	0b00011111,
}; ///< Lista com a configuração do led de 7 segmentos para cada número de vidas

/**
 * Atualiza o valor do display de 7 segmentos que representa a vida
 */ 
void updateLife() {
	uint8_t value = lifeDisplay[life];
	uint8_t bitA = value & 0b00000001;
	setBit(&PORTB, SEG_A, bitA);
	PORTC = (PORTC & 0b11000001) | (value & 0b00111110);
}

/**
 * Remove uma vida e realiza a rotina de perda de vida (rodar 180 graus e desativar por 5 segundos)
 * Caso não existam mais vidas para remover, desliga os motores e seta @param alive para 0
 */ 
void removeLife() {
	if(alive) {
		if(life > 0){
			writeUSART("Removendo uma Vida");
			life -= 1;
			updateLife();
			setMotor1(1, 0, 255);
			setMotor2(0, 1, 255);
			_delay_ms(TIME_180);
			setMotor1(0, 0, 0);
			setMotor2(0, 0, 0);
			_delay_ms(5000);
		}else{
			alive = 0;
			setMotor1(0, 0, 0);
			setMotor2(0, 0, 0);
		}
	}
}

/**
 * Recarrega as vidas para o valor máximo e seta  @param alive para 1
 */
void resetLife() {
	writeUSART("Resetando Vidas");
	life = maxLife;
	alive = 1;
	updateLife();
}

/**
 * Configura e inicia o conversor analógico digital
 */
void setupADC() {
    ADMUX = (1 << REFS0); 
    ADCSRA = (1 << ADEN) | (1 << ADPS2) | (1 << ADPS1) | (1 << ADPS0);
}

/**
 * Aguarda a conversão e retorna a leitura do conversor analógico digital para o pino PC0
 * @return leitura do pino PC0 de 10 bits (0–1023)
 */
uint16_t readLDR() {
    ADMUX = (ADMUX & 0xF0) | 0; 
    ADCSRA |= (1 << ADSC);
    while (ADCSRA & (1 << ADSC));
    return ADC;
}

/**
 * Função de configuração principal, seta os pinos como saída ou entrada e chama as funções de setup
 */
void start(){
	setupUSART(9600);
	
	writeUSART("START\n");
	//SEGMENTOS
	DDRC |= (1 << SEG_B) | (1 << SEG_C) | (1 << SEG_D) | (1 << SEG_E) | (1 << SEG_G);
	DDRB |= (1 << SEG_A);
	
	//MOTOR
	DDRB |= (1 << MOTOR1_A) | (1 << MOTOR1_B) | (1 << MOTOR2_A) | (1 << MOTOR2_PWM);
	DDRD |= (1 << MOTOR1_PWM) | (1 << MOTOR2_B);
	
	//LASER
	DDRD |= (1 << LASER);
	
	writeUSART("SETANDO PWM MOTORES \n");
	setupMotorsPwm();
	
	writeUSART("SETANDO ADC LDR \n");
	setupADC();
	
	writeUSART("SETANDO LASER TIMER \n");
	setupLaserTimer();
	
	resetLife();
	
	sei();
	UCSR0B |= RX_COMPLETE_INTERRUPT;
}

int SPEED = 200; ///< Valor da velocidade do carrinho
volatile uint8_t dataUSART; ///< Byte que guarda a mensagem que vai ser lida pelo USART

/**
 * Interrupção que lida com as mensagens do USART, interpretando os dados para controlar o robô
 */
ISR(USART_RX_vect){
	if(alive){
		dataUSART = UDR0;
		
		if(dataUSART == 'f'){
			writeUSART("MOVENDO FRENTE \n");
			setMotor1(1, 0, SPEED);
			setMotor2(1, 0, SPEED);
		}
		else if(dataUSART == 'b'){
			writeUSART("MOVENDO TRAZ \n");
			setMotor1(0, 1, SPEED);
			setMotor2(0, 1, SPEED);
		}
		else if(dataUSART == 'l'){
			writeUSART("MOVENDO ESQ \n");
			setMotor1(1, 0, SPEED);
			setMotor2(0, 0, 0);
		}
		else if(dataUSART == 'r'){
			writeUSART("MOVENDO DIR \n");
			setMotor1(0, 0, 0);
			setMotor2(1, 0, SPEED);
		}
		else if(dataUSART == 'p'){
			writeUSART("PARANDO \n");
			setMotor1(0, 0, 0);
			setMotor2(0, 0, 0);
		}
		else if(dataUSART == 'm'){
			writeUSART("LASER ENTRANDO EM MODO MANUAL \n");
			laserAuto = 0;
		}
		else if(dataUSART == 'a'){
			writeUSART("LASER ENTRANDO EM MODO AUTOMATICO \n");
			laserAuto = 1;
		}
		else if(dataUSART == 's'){
			if(laserAuto){
				writeUSART("LASER AUTOMATICO NAO PODE ATIRAR \n");
			}else{
				writeUSART("ATIRANDO \n");
				shoot();
			}
			
		}else if(dataUSART == '0'){
			writeUSART("VIRANDO BUNDA\n");
			setMotor1(1, 0, 255);
			setMotor2(0, 1, 255);
			_delay_ms(TIME_180);
			setMotor1(0, 0, 0);
			setMotor2(0, 0, 0);
		}
		else if(dataUSART == '1'){
			writeUSART("CABEÇADA\n");
			setMotor1(1, 0, 255);
			setMotor2(1, 0, 255);
			_delay_ms(100);
			setMotor1(0, 0, 0);
			setMotor2(0, 0, 0);
		}else if(dataUSART == '!'){
			if(debug) {
				writeUSART("DEBUG DESLIGADO\n");
			}else{
				writeUSART("DEBUG LIGADO\n");
			}
			debug = !debug;
		}else if(dataUSART == '3'){
			resetLife();
		}else if(dataUSART == '+'){
			SPEED += 10;
			if(SPEED > 255){
				SPEED = 255;
			}
		}
		else if(dataUSART == '-'){
			SPEED -= 10;
			if(SPEED < 0){
				SPEED = 0;
			}
		}else if(dataUSART == 'h'){
			writeUSART("--COMANDOS--\n");
			writeUSART("f | mover frente\n");
			writeUSART("b | mover tras\n");
			writeUSART("l | mover esquerda\n");
			writeUSART("r | mover direita\n");
			writeUSART("p | parar motores\n");
			writeUSART("m | laser manual\n");
			writeUSART("s | atirar laser manual\n");
			writeUSART("a | laser automatico [PADRAO]\n");
			writeUSART("0 | giro 180\n");
			writeUSART("1 | avanço\n");
			writeUSART("3 | resetar\n");
			writeUSART("+ / - | ajustar velocidade \n");
		}
	}
	
	
}

#define LDR_THRESHOLD 900  ///< Valor mínimo de detecção do LDR
char buffer[6]; ///< Buffer 6 bytes para guardar valor lido do LDR convertido para String

/**
 * Função de Entrada
*/
int main(void){
	start();
	while(1){
			uint16_t ldrValue = readLDR();
			if(debug){
				int i = 0;
				int temp = ldrValue;
				do {
					buffer[i++] = (temp % 10) + '0';
					temp /= 10;
				} while (temp > 0);
			
				buffer[i] = '\0';
				for(int j=0; j<i/2; j++){
					char t = buffer[j];
					buffer[j] = buffer[i-1-j];
					buffer[i-1-j] = t;
				}
				writeUSART("LDR:"); writeUSART(buffer);
			}
			
			if(ldrValue > LDR_THRESHOLD){
				removeLife();
			}	
	}
	
	return 0;
}
